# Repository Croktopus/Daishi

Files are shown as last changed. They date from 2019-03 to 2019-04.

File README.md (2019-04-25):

# Daishi

http://kb.metamechs.com/daishi/

I'm redesigning the Daishi-Prime (Daishi case that uses a plate), so stay tuned for that I guess.

If you're interested in designing your own keyboard, I recommend https://github.com/ruiqimao/keyboard-pcb-guide to learn PCB design, https://beta.docs.qmk.fm/ for how to use QMK, and https://www.youtube.com/watch?v=A5bc9c3S12g&list=PL40d7srwyc_Ow4aaOGXlP2idPGwD7ruKg to get started with Fusion 360.

Other invaluable resources:
* http://www.keyboard-layout-editor.com/ to design your layout
* http://builder.swillkb.com/ to generate a plate (though I do recommend doing it manually if it's going to be more complex than a rectangle with a few holes)
* https://discordapp.com/invite/Uq7gcHh for the QMK discord (super helpful folks who are way better at this than me)
* https://www.laserboost.com/ to get a metal plate cut
* https://www.ponoko.com/ to get an acrylic plate cut
* https://jlcpcb.com/ cheapest PCB manufacturer I've found

Check the BoM to find links to places where you can buy all the components for cheaper than I was able to.

All I ask is that if you do build one of these please send me pics!

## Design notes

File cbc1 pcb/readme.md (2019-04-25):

# Making a PCB

If you just want to have a CBC1 PCB printed, you'll want to take the gerbers.zip file to your PCB fab of choice (I recommend JLCPCB for the price), as well as the gerbers.zip in the daughterboard directory.

I've also got all the KiCad files in here if you want to play around with making your own modifications.

Once you have your PCB (unless you got it assembled for you), you get to do all the super fun SMT soldering! This is easily the worst part of the process IMO, but you can get through it in a few hours. If you haven't done this before, look up some youtube tutorials before you decide whether you want to.

Then you can tune your stabs, crimp a cable, and solder some switches (I recommend following Nathan Kim's guide for stabilizers, just without the band-aid mod).

Obviously this is super light on details, but...anything in here that you don't know how to do, just look it up. If you're still having trouble understanding something, I can answer some questions, but there are some fairly deep topics in here that already have great educational resources (EEVBlog for soldering, https://github.com/ruiqimao/keyboard-pcb-guide for KiCad, Nathan Kim's vids and streams for keeb building).

But that's pretty much the gist of it for getting a functional PCB for your Daishi build.

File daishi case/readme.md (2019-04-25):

# Building a Case

This should just be a (relatively) quick guide on how to create a case for a Daishi, which ended up being super complex.

Step 1 is 3D printing the pieces. If you have access to a large enough 3D printer, you can just print the top and bottom as complete pieces using the .stl's in this folder.

If you are a mere mortal like me, you'll have to split up both the top and bottom case into a few pieces each. I included some .stl's that have been pre-split into pieces small enough to fit near any 3D printer, with dovetails to make alignment easier.

I print at ~50% infill (I try to push it as high as possible, but at around the 75% mark I start to get severe issues with print quality), with a brim, and 0.2mm layer height (could bump it up to 0.3 without a real loss in quality). A problem with printing in multiple dovetailed pieces is that fitment has to be pretty precise, and brims can fuck that up if not removed carefully. You can get away with whatever blade you have on hand, but I recommend using a metal deburring tool like https://smile.amazon.com/Acrux7-Deburring-Remover-Plastic-Aluminum/dp/B077Z4T437/ if you're going to be doing this a lot - it's been a big improvement to my 3D printing QoL.

After you have the pieces, you'll want to ensure they all fit together nicely and glue them together (I recommend a medium or thicker CA glue). This is also where I'd recommend painting, if you want to do so.

Use a soldering iron to put in your brass threaded inserts (links in the BoM). You could try to secure 3D printed components with something like wood screws, but I wouldn't recommend it. Brass threaded inserts are going to be way more durable than any threads you tap in plastic, which will allow you to actually take it apart and put it back together a few times. Plus you can actually get some clamp with these threaded inserts, which is pretty important for a build with gasketing.

This is "optional", but it makes a huge difference. Take some 1.75mm transparent filament and shove it in the holes for the lock lights, using a flush cutter to get the top flush with the top of the top case (make sure the filament ends a few mm above the bottom of the hole, so that there's room for the LED). This makes for a really nice looking light pipe, and when the lights are off it almost just looks like the case material; I love the aesthetic.

Now it's time to apply the gasketing. Take your rubber of choice (I use neoprene, but It also works with EPDM and probably silicone and most any other rubber too) and start punching out holes. I got this cheap set off amazon https://smile.amazon.com/gp/product/B07BT47968 but the only sizes you need are 5mm, 2mm, and 7mm (and really 95% of the work is done with the 5mm punch, with the others only used for the standoffs with screw holes). Cut out a bunch of strips of rubber to go around the edge of the bottom case and the bottom of the top case (as seen in the photos), and glue everything in!

I use some blu-tack to hold down my cable that goes to the USB daughterboard (velcro would be nicer but I only had hooks on hand and no loops!)

You'll need 8 M3x12 screws for joining the top and bottom case, and 11 M2x4 screws to mount the keyboard PCB and daughterboard (though you could also forgo the 7 screws for the keyboard PCB and just rely on the gasketing). I also recommend using M2 fiber washers for the PCB screws (linked in the BoM).

That's pretty much it for building the case. Good luck!

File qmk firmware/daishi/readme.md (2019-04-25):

# Daishi

Daishi

A compact battlecruiser using the CBC1 PCB. [More info on kb.metamechs.com](http://kb.metamechs.com/daishi/)

Keyboard Maintainer: [Crokto](https://github.com/Croktopus/)  
Hardware Supported: CBC1 PCB  
Hardware Availability: [kb.metamechs.com](http://kb.metamechs.com/daishi/get-your-own-daishi/)

Make example for this keyboard (after setting up your build environment):

    make daishi:default

See the [build environment setup](https://docs.qmk.fm/#/getting_started_build_tools) and the [make instructions](https://docs.qmk.fm/#/getting_started_make_guide) for more information. Brand new to QMK? Start with our [Complete Newbs Guide](https://docs.qmk.fm/#/newbs).

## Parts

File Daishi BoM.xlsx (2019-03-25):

PCB |  |  |  |  |  |  | CASE |  |  |  |  |  |  | TIME
part | qty | link | price/ea | moq | extended price | qty price | product | qty | link | $/ea | moq | extended price | qty price | activity | hours | rate | total pay
.1u cap | 6 | https://lcsc.com/product-detail/Others_CCTC-TCC0805X7R104M500DT_C360619.html | 0.0046 | 50 | 0.23 | 0.0276 | m2 inserts | 11 | https://itworks3d.com/product/metric-brass-heat-set-insert-plastics/ | 0.21 | 1 | 2.31 | 2.31 | smd | 3.5 | 11 | 38.5
1u cap | 2 | https://lcsc.com/product-detail/Multilayer-Ceramic-Capacitors-MLCC-SMD-SMT_SAMSUNG_CL21F105ZOFNNNE_1uF-105-80-20-16V_C16834.html | 0.01 | 50 | 0.405 | 0.0162 | m3 inserts | 8 | https://itworks3d.com/product/metric-brass-heat-set-insert-plastics/ | 0.31 | 1 | 2.48 | 2.48 | tht | 1.5 | 11 | 16.5
22p cap | 2 | https://lcsc.com/product-detail/Multilayer-Ceramic-Capacitors-MLCC-SMD-SMT_22pF-220-5-50V_C24658.html | 0.01 | 50 | 0.3 | 0.012 | filament | 2 | https://www.matterhackers.com/store/l/175mm-pla-filament-grey-1-kg/sk/MPL0Q8ZD | 18.99 | 1 | 37.98 | 37.98 | case building | 1.5 | 11 | 16.5
4.7n cap | 1 | https://lcsc.com/product-detail/Multilayer-Ceramic-Capacitors-MLCC-SMD-SMT_MuRata_GRM2162C1H472JA01D_4-7nF-472-5-50V_C86029.html | 0.03 | 20 | 0.58 | 0.029 | neoprene | 1 | https://smile.amazon.com/gp/product/B076MHP8WJ/ref=ppx_yo_dt_b_asin_title_o03_s00?ie=UTF8&psc=1 | 11.68 | 1 | 11.68 | 11.68 | 3d printing | 80 | 0.5 | 40
10k res | 2 | https://lcsc.com/product-detail/Chip-Resistor-Surface-Mount_10KR-1002-1_C103904.html | 0.0018 | 100 | 0.18 | 0.0036 | sorbothane feet | 1 | https://smile.amazon.com/gp/product/B00YLLRMK0/ref=oh_aui_search_asin_title?ie=UTF8&psc=1 | 0.443 | 36 | 15.948 | 0.443
1k res | 4 | https://lcsc.com/product-detail/Chip-Resistor-Surface-Mount_1KR-1001-1_C103903.html | 0.0019 | 100 | 0.19 | 0.0076 | velcro | 1 | https://smile.amazon.com/PASS-IPass-FastLane-Mounting-Kit/dp/B01N5EH7R9?s=hi | 7.15 | 1 | 7.15 | 7.15 |  |  |  | 111.5
22 res | 2 | https://lcsc.com/product-detail/Others_Huaxin-S-T-WR08X22R0FTL_C334886.html | 0.0017 | 100 | 0.17 | 0.0034 | transparent filament (light pipes, optional) | 1 | https://smile.amazon.com/3D-Solutech-Filament-Dimensional-Accuracy/dp/B00MB3CV6K/ | 17.99 | 1 | 17.99 | 17.99
5.1k res | 2 | https://lcsc.com/product-detail/Chip-Resistor-Surface-Mount_5-1KR-5101-1_C84375.html | 0.0025 | 100 | 0.25 | 0.005 | m2 screws | 11 | https://smile.amazon.com/uxcell-M2x4mm-Thread-Button-Socket/dp/B01B1OD83Y?s=industrial | 0.0762 | 100 | 7.62 | 0.8382
1M res | 1 | https://lcsc.com/product-detail/Chip-Resistor-Surface-Mount_1MR-1004-1_C136578.html | 0.0017 | 100 | 0.17 | 0.0017 | m3 screws | 8 | https://smile.amazon.com/uxcell-M3x12mm-Socket-Screws-100Pcs/dp/B0143GZIHQ?s=industrial | 0.0999 | 100 | 9.99 | 0.7992
diode | 117 | https://lcsc.com/product-detail/Switching-Diode_1N4148W_C115103.html | 0.01 | 50 | 0.819 | 0.819
0805 led | 3 | https://lcsc.com/product-detail/Light-Emitting-Diodes-LED_Hongli-Zhihui-HONGLITRONIC-HL-PSC-2012H233W-8000-12000K_C219230.html | 0.03 | 20 | 0.532 | 0.0798 |  |  |  |  |  | 113.148 | 81.6704
rst sw | 1 | https://www.digikey.com/product-detail/en/e-switch/TL3342F160QG-TR/EG2531CT-ND/379004 | 0.65 | 1 | 0.65 | 0.65
90usb1286 | 1 | https://www.digikey.com/product-detail/en/microchip-technology/AT90USB1286-AU/AT90USB1286-AU-ND/2238141 | 8.09 | 1 | 8.09 | 8.09 |  |  |  |  |  |  |  | SHIPPING
16M xtal | 1 | https://www.digikey.com/product-detail/en/epson/FA-238-16.0000MB-C3/SER3686CT-ND/2403459 | 0.36 | 1 | 0.36 | 0.36 |  |  |  |  |  |  |  | source | total | # you net | $per
hro usbc | 1 | https://lcsc.com/product-detail/USB-Type-C_Korean-Hroparts-Elec-TYPE-C-31-M-12_C165948.html | 0.39 | 1 | 0.3882 | 0.3882 |  |  |  |  |  |  |  | lcsc | 5.18 | 5 | 1.036
1x4 recep | 2 | https://www.digikey.com/product-detail/en/te-connectivity-amp-connectors/280378-1/A106404-ND/1153244 | 0.93 | 1 | 1.86 | 1.86 |  |  |  |  |  |  |  | digikey | 13 | 5 | 2.6
1x4 plug | 2 | https://www.digikey.com/product-detail/en/te-connectivity-amp-connectors/280359/A121744-ND/2054280 | 0.35 | 1 | 0.7 | 0.7 |  |  |  |  |  |  |  | mouser | 7.99 | 5 | 1.598
crimp conn | 8 | https://www.digikey.com/product-detail/en/te-connectivity-amp-connectors/280708-2/A107044CT-ND/3488605 | 0.14 | 1 | 1.12 | 1.12 |  |  |  |  |  |  |  | IT-works | 11.15 | 5 | 2.23
1x4 wire | 1 | https://www.digikey.com/product-detail/en/adafruit-industries-llc/3892/1528-2695-ND/9603618 | 1.95 | 1 | 1.95 | 1.95 |  |  |  |  |  |  |  | jlcpcb | 16.98 | 5 | 3.396
 |  |  |  |  |  |  |  |  | you do the work |  | 333.0222 |  |  | novelkeys | 3.85 | 5 | 0.77
alps encoder | 1 | https://www.mouser.com/ProductDetail/688-EC11E1834403 | 5.38 | 1 | 5.38 | 5.38 |  |  | I do the work |  | 295.2972
keys witches | 116 | https://www.aliexpress.com/item/VK-JAPAN-SMK-original-New-genuine-imported-keyboard-switch-button-touch-2-foot-reset-switch/32845423584.html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 | 0.444 | 200 | 88.8 | 51.504 |  |  |  |  |  |  |  |  | 58.15 |  | 11.63
2u stabs | 4 | https://novelkeys.xyz/collections/miscellaneous/products/cherry-stabilizers?variant=3747938893864 | 2.00 | 1 | 8 | 8
6.25u stabs | 1 | https://novelkeys.xyz/collections/miscellaneous/products/cherry-stabilizers?variant=3747938893864 | 2.25 | 1 | 2.25 | 2.25
m2 washers | 21 | https://smile.amazon.com/gp/product/B01ARADX88/ref=oh_aui_search_asin_title?ie=UTF8&psc=1 | 0.07 | 100 | 6.97 | 1.4637
main pcb | 1 | https://jlcpcb.com/ | 5.276 | 5 | 26.38 | 5.276
daughterboard | 1 | https://jlcpcb.com/ | 0.5 | 10 | 5 | 0.5 | SHIPPING MATS
 |  |  |  |  |  |  | item | link | total | # netted | $per
 |  |  |  |  | 161.7242 | 90.4968 | kaizen | https://smile.amazon.com/gp/product/B007J2JJYK/ref=ppx_od_dt_b_asin_title_s00?ie=UTF8&psc=1 | 24.99 | 2 | 12.495
 |  |  |  |  |  |  | boxes | https://www.globalindustrial.com/product/itemKey/30396942 | 16.75 | 25 | 0.67
 |  |  |  |  |  |  |  |  |  |  | 13.165

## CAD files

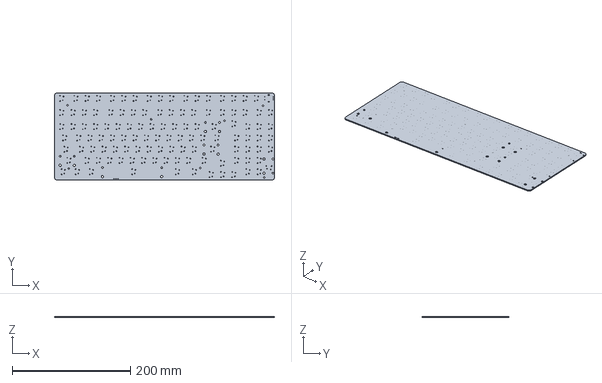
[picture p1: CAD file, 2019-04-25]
cbc1 pcb/cbc1.step
371.5 x 147.6 x 1.60 mm

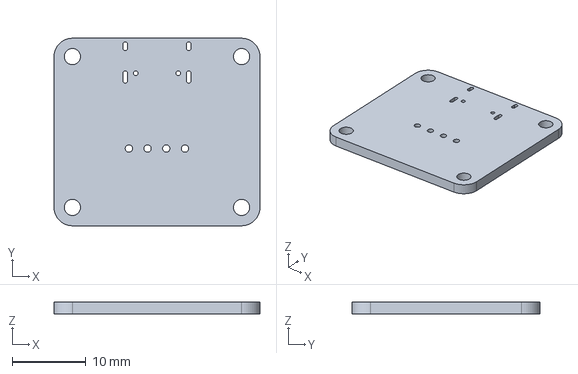
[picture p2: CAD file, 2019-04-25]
cbc1 pcb/usb breakout v2/usb breakouts.step
28.0 x 25.5 x 1.60 mm

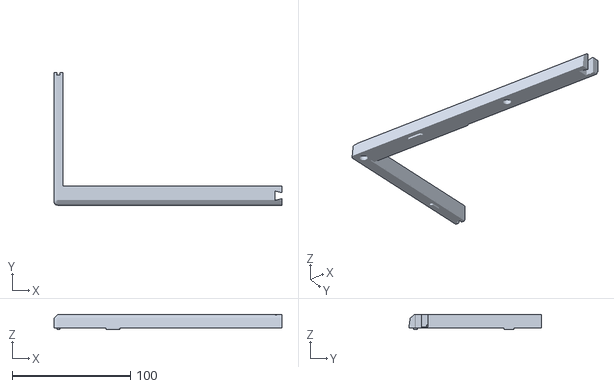
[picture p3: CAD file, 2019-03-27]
daishi case/3 way split for 3d printing/top se.stl
192.9 x 112.2 x 12.3

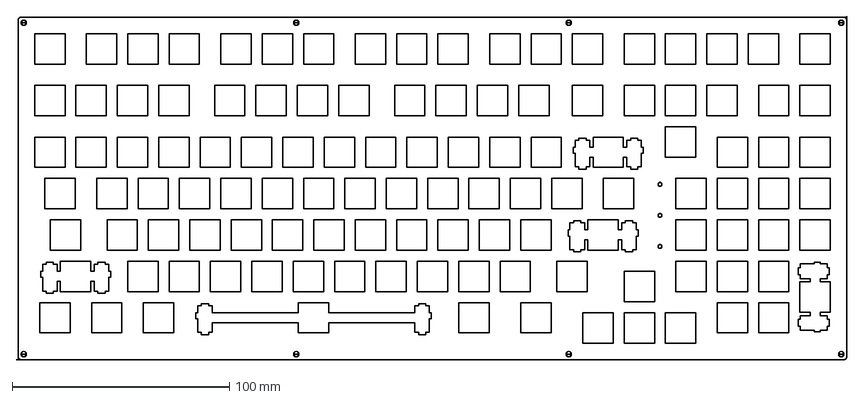
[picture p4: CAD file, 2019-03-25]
daishi case/plate.dxf
382.4 x 158.0 mm

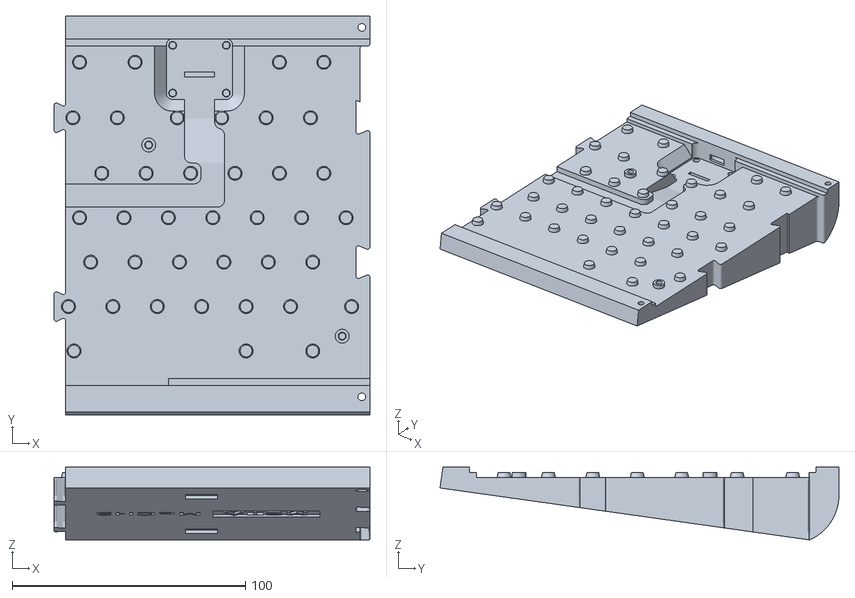
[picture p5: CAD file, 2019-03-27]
daishi case/3 way split for 3d printing/bot mid.stl
135.5 x 171.1 x 31.2

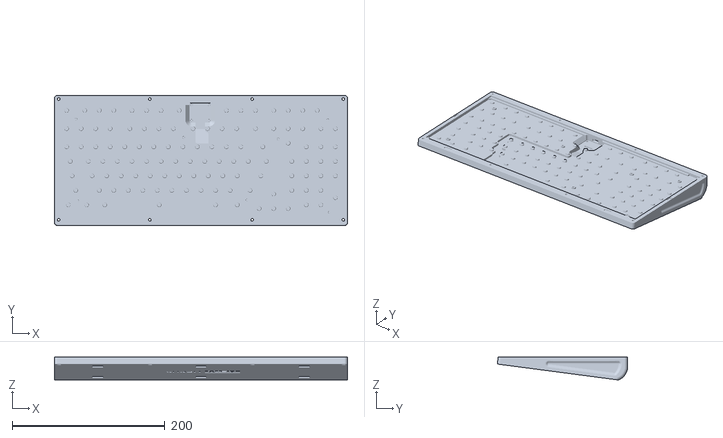
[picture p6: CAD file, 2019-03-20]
daishi case/daishi bottom case.stl
384.2 x 171.0 x 30.2

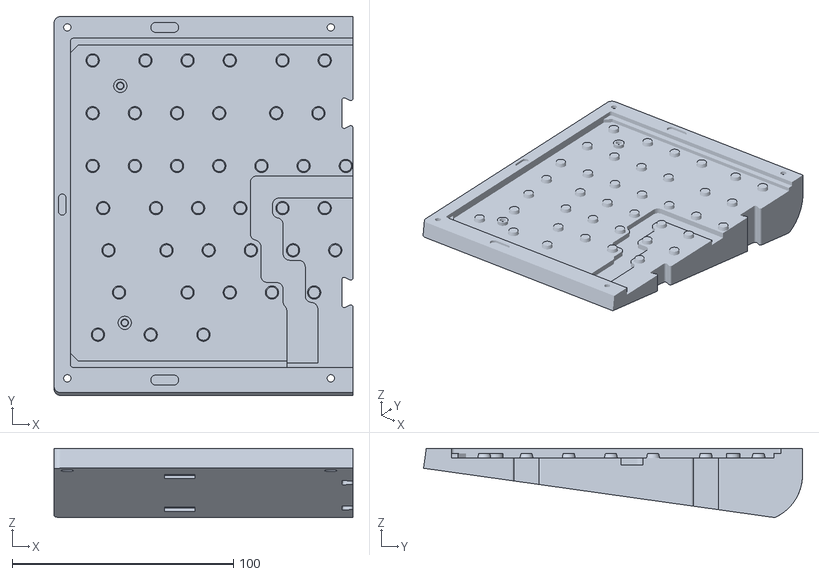
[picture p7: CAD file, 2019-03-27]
daishi case/3 way split for 3d printing/bot left.stl
135.0 x 171.1 x 31.2

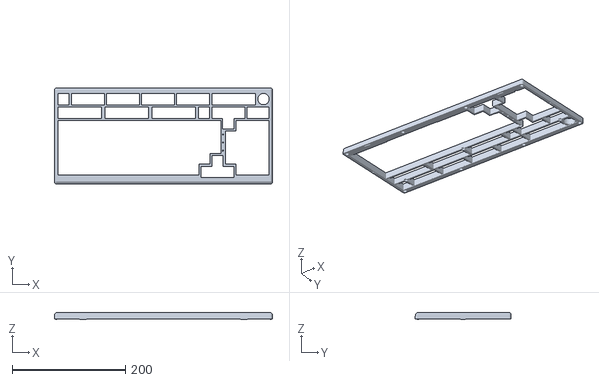
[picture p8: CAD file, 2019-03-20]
daishi case/daishi top case.stl
384.2 x 169.8 x 12.6

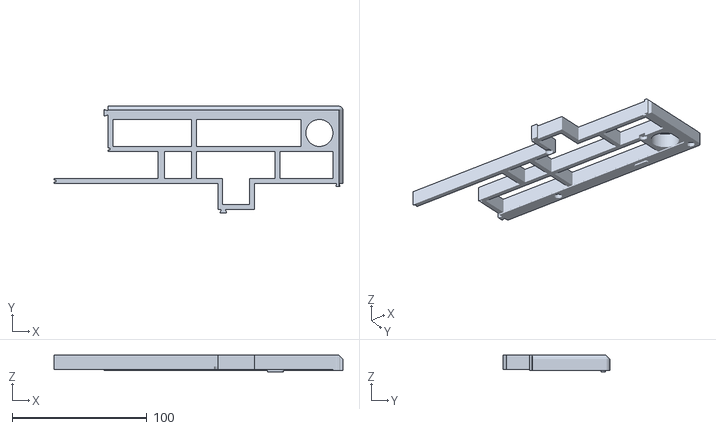
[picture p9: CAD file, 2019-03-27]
daishi case/3 way split for 3d printing/top nw.stl
214.2 x 79.0 x 12.3

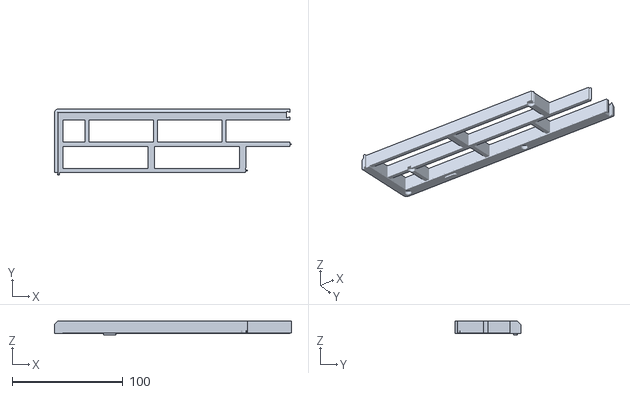
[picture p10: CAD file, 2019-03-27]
daishi case/3 way split for 3d printing/top ne.stl
214.4 x 59.4 x 12.3

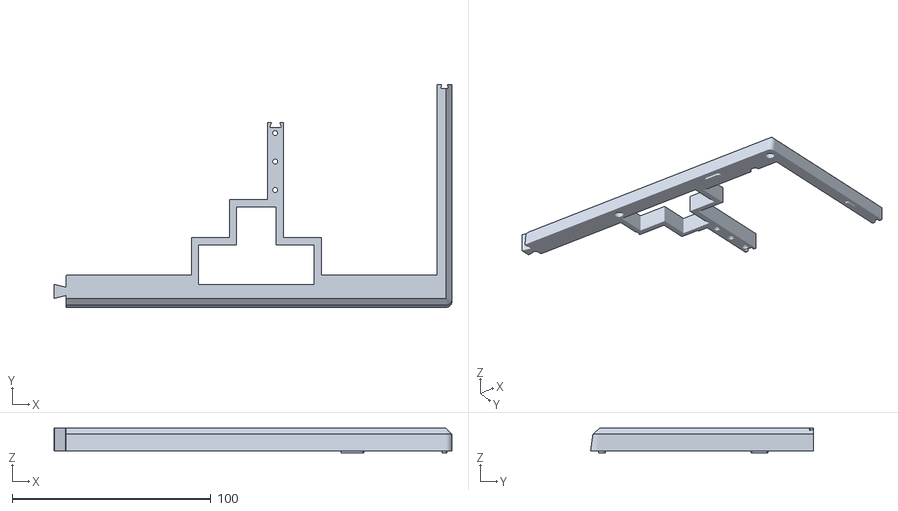
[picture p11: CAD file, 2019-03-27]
daishi case/3 way split for 3d printing/top sw.stl
200.1 x 112.1 x 12.3

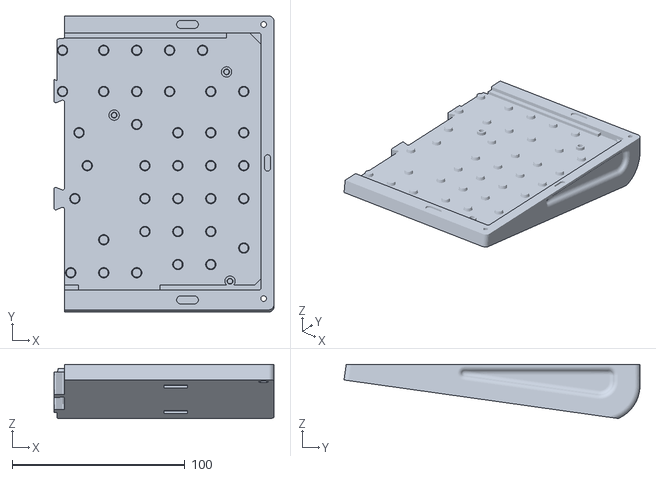
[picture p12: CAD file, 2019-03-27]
daishi case/3 way split for 3d printing/bot right.stl
127.2 x 171.1 x 31.2

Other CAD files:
daishi case/daishi.f3d

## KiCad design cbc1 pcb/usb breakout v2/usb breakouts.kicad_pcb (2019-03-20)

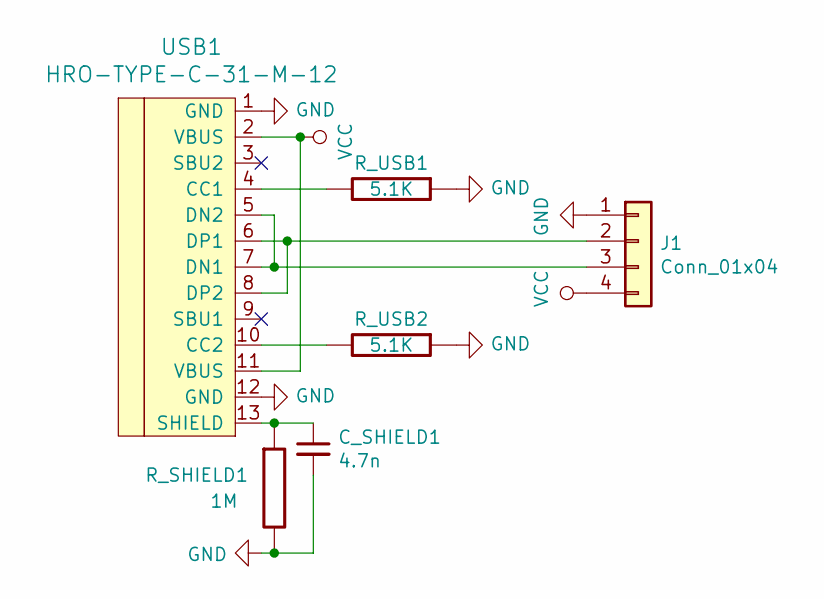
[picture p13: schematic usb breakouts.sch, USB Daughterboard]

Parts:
C_SHIELD1: 4.7n; C_0805_HandSoldering
J1: Conn_01x04; Pin_Header_Angled_1x04_Pitch2.54mm_centered
R_SHIELD1: 1M; R_0805_HandSoldering
R_USB1, R_USB2: 5.1K; R_0805_HandSoldering
USB1: HRO-TYPE-C-31-M-12; HRO-TYPE-C-31-M-12-HandSoldering

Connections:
GND: C_SHIELD1.2, J1.1, R_SHIELD1.2, R_USB1.1, R_USB2.1, USB1.1 (GND), USB1.12 (GND)
unnamed: C_SHIELD1.1, R_SHIELD1.1, USB1.13 (SHIELD)
unnamed: J1.2, USB1.6 (DP1), USB1.8 (DP2)
unnamed: J1.3, USB1.5 (DN2), USB1.7 (DN1)
unnamed: R_USB1.2, USB1.4 (CC1)
unnamed: R_USB2.2, USB1.10 (CC2)
VCC: J1.4, USB1.2 (VBUS), USB1.11 (VBUS)

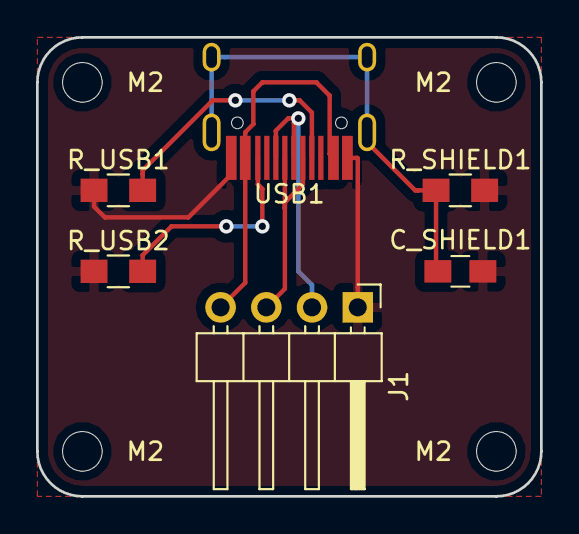
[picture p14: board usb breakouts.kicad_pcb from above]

Board: 2 copper layers, 28.0 x 25.5 mm, 10 parts (0 on the bottom side), 7 nets.

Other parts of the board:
M2, M2#2, M2#3, M2#4: MountingHole_2.2mm_M2

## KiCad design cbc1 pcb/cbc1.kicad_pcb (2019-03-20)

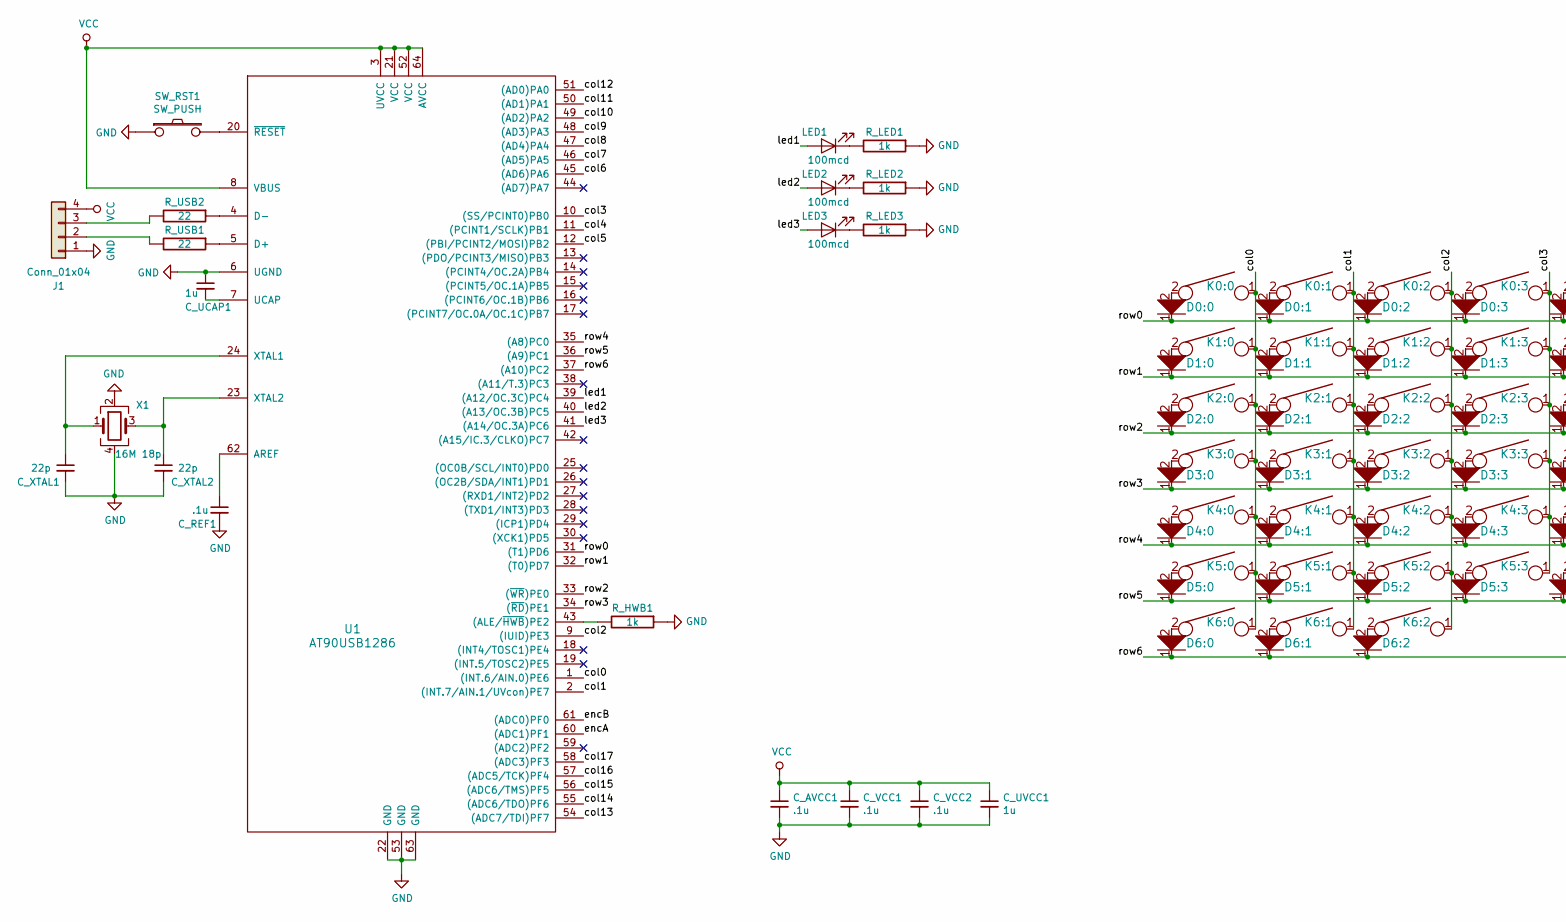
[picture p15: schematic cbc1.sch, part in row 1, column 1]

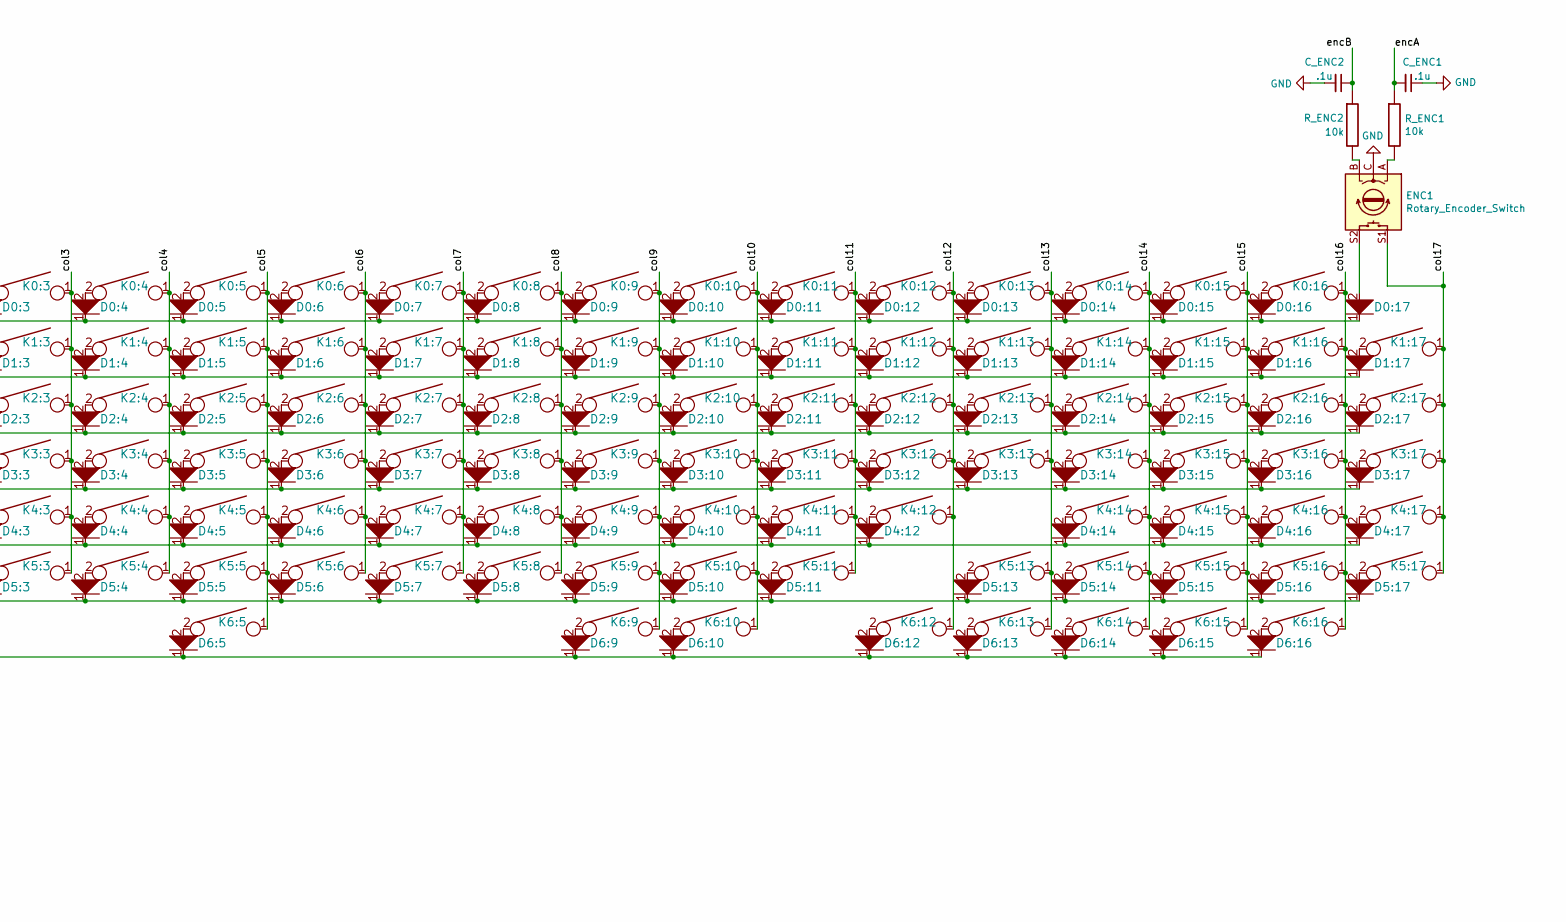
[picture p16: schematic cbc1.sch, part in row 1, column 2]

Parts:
C_AVCC1: .1u; C_0805_HandSoldering
C_ENC1, C_ENC2: .1u; C_0805_HandSoldering
C_REF1: .1u; C_0805_HandSoldering
C_UCAP1: 1u; C_0805_HandSoldering
C_UVCC1: 1u; C_0805_HandSoldering
C_VCC1, C_VCC2: .1u; C_0805_HandSoldering
C_XTAL1, C_XTAL2: 22p; C_0805_HandSoldering
D0:0, D0:1, D0:2, D0:3, D0:4, D0:5, D0:6, D0:7, D0:8, D0:9, D0:10, D0:11, D0:12, D0:13, D0:14, D0:15, D0:16, D0:17, D1:0, D1:1, D1:2, D1:3, D1:4, D1:5, D1:6, D1:7, D1:8, D1:9, D1:10, D1:11, D1:12, D1:13, D1:14, D1:15, D1:16, D1:17, D2:0, D2:1, D2:2, D2:3, D2:4, D2:5, D2:6, D2:7, D2:8, D2:9, D2:10, D2:11, D2:12, D2:13, D2:14, D2:15, D2:16, D2:17, D3:0, D3:1, D3:2, D3:3, D3:4, D3:5, D3:6, D3:7, D3:8, D3:9, D3:10, D3:11, D3:12, D3:13, D3:14, D3:15, D3:16, D3:17, D4:0, D4:1, D4:2, D4:3, D4:4, D4:5, D4:6, D4:7, D4:8, D4:9, D4:10, D4:11, D4:12, D4:14, D4:15, D4:16, D4:17, D5:0, D5:1, D5:2, D5:3, D5:4, D5:5, D5:6, D5:7, D5:8, D5:9, D5:10, D5:11, D5:13, D5:14, D5:15, D5:16, D5:17, D6:0, D6:1, D6:2, D6:5, D6:9, D6:10, D6:12, D6:13, D6:14, D6:15, D6:16: D; D_SOD123_hand
ENC1: Rotary_Encoder_Switch; RotaryEncoder_Alps_EC11E-Switch_Vertical_H20mm
J1: Conn_01x04; Pin_Header_Angled_1x04_Pitch2.54mm
K0:0, K0:1, K0:2, K0:3, K0:4, K0:5, K0:6, K0:7, K0:8, K0:9, K0:10, K0:11, K0:12, K0:13, K0:14, K0:15, K0:16, K1:0, K1:1, K1:2, K1:3, K1:4, K1:5, K1:6, K1:7, K1:8, K1:9, K1:10, K1:11, K1:12, K1:13, K1:14, K1:15, K1:16, K1:17, K2:0, K2:1, K2:2, K2:3, K2:4, K2:5, K2:6, K2:7, K2:8, K2:9, K2:10, K2:11, K2:12, K2:14, K2:15, K2:16, K2:17, K3:1, K3:2, K3:3, K3:4, K3:5, K3:6, K3:7, K3:8, K3:9, K3:10, K3:11, K3:12, K3:14, K3:15, K3:16, K3:17, K4:1, K4:2, K4:3, K4:4, K4:5, K4:6, K4:7, K4:8, K4:9, K4:10, K4:11, K4:14, K4:15, K4:16, K4:17, K5:1, K5:2, K5:3, K5:4, K5:5, K5:6, K5:7, K5:8, K5:9, K5:10, K5:13, K5:14, K5:15, K5:16, K6:12, K6:13, K6:14, K6:15, K6:16: KEYSW; SMK-PCB-100-90deg
K2:13, K5:17: KEYSW; SMK-PCB-200-90deg
K3:0, K3:13, K6:9, K6:10: KEYSW; SMK-PCB-150-90deg
K4:0, K5:11: KEYSW; SMK-PCB-175-90deg
K4:12, K5:0: KEYSW; SMK-PCB-225-90deg
K6:0, K6:1, K6:2: KEYSW; SMK-PCB-125-90deg
K6:5: KEYSW; SMK-PCB-625-90deg
LED1, LED2, LED3: 100mcd; LED_0805_HandSoldering
R_ENC1, R_ENC2: 10k; R_0805_HandSoldering
R_HWB1: 1k; R_0805_HandSoldering
R_LED1, R_LED2, R_LED3: 1k; R_0805_HandSoldering
R_USB1, R_USB2: 22; R_0805_HandSoldering
SW_RST1: SW_PUSH; SW_SPST_TL3342
U1: AT90USB1286; TQFP-64_14x14mm_Pitch0.8mm
X1: 16M 18p; Crystal_SMD_SeikoEpson_FA238-4pin_3.2x2.5mm_HandSoldering

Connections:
/col0: K0:0.1, K1:0.1, K2:0.1, K3:0.1, K4:0.1, K5:0.1, K6:0.1, U1.1 ((INT.6/AIN.0)PE6)
/col1: K0:1.1, K1:1.1, K2:1.1, K3:1.1, K4:1.1, K5:1.1, K6:1.1, U1.2 ((INT.7/AIN.1/UVcon)PE7)
/col2: K0:2.1, K1:2.1, K2:2.1, K3:2.1, K4:2.1, K5:2.1, K6:2.1, U1.9 ((IUID)PE3)
/col3: K0:3.1, K1:3.1, K2:3.1, K3:3.1, K4:3.1, K5:3.1, U1.10 ((SS/PCINT0)PB0)
/col4: K0:4.1, K1:4.1, K2:4.1, K3:4.1, K4:4.1, K5:4.1, U1.11 ((PCINT1/SCLK)PB1)
/col5: K0:5.1, K1:5.1, K2:5.1, K3:5.1, K4:5.1, K5:5.1, K6:5.1, U1.12 ((PBI/PCINT2/MOSI)PB2)
/col6: K0:6.1, K1:6.1, K2:6.1, K3:6.1, K4:6.1, K5:6.1, U1.45 ((AD6)PA6)
/col7: K0:7.1, K1:7.1, K2:7.1, K3:7.1, K4:7.1, K5:7.1, U1.46 ((AD5)PA5)
/col8: K0:8.1, K1:8.1, K2:8.1, K3:8.1, K4:8.1, K5:8.1, U1.47 ((AD4)PA4)
/col9: K0:9.1, K1:9.1, K2:9.1, K3:9.1, K4:9.1, K5:9.1, K6:9.1, U1.48 ((AD3)PA3)
/col10: K0:10.1, K1:10.1, K2:10.1, K3:10.1, K4:10.1, K5:10.1, K6:10.1, U1.49 ((AD2)PA2)
/col11: K0:11.1, K1:11.1, K2:11.1, K3:11.1, K4:11.1, K5:11.1, U1.50 ((AD1)PA1)
/col12: K0:12.1, K1:12.1, K2:12.1, K3:12.1, K4:12.1, K6:12.1, U1.51 ((AD0)PA0)
/col13: K0:13.1, K1:13.1, K2:13.1, K3:13.1, K5:13.1, K6:13.1, U1.54 ((ADC7/TDI)PF7)
/col14: K0:14.1, K1:14.1, K2:14.1, K3:14.1, K4:14.1, K5:14.1, K6:14.1, U1.55 ((ADC6/TDO)PF6)
/col15: K0:15.1, K1:15.1, K2:15.1, K3:15.1, K4:15.1, K5:15.1, K6:15.1, U1.56 ((ADC6/TMS)PF5)
/col16: K0:16.1, K1:16.1, K2:16.1, K3:16.1, K4:16.1, K5:16.1, K6:16.1, U1.57 ((ADC5/TCK)PF4)
/col17: ENC1.S1, K1:17.1, K2:17.1, K3:17.1, K4:17.1, K5:17.1, U1.58 ((ADC3)PF3)
/encA: C_ENC1.2, R_ENC1.1, U1.60 ((ADC1)PF1)
/encB: C_ENC2.1, R_ENC2.1, U1.61 ((ADC0)PF0)
/led1: LED1.2 (A), U1.39 ((A12/OC.3C)PC4)
/led2: LED2.2 (A), U1.40 ((A13/OC.3B)PC5)
/led3: LED3.2 (A), U1.41 ((A14/OC.3A)PC6)
/row0: D0:0.1, D0:1.1, D0:2.1, D0:3.1, D0:4.1, D0:5.1, D0:6.1, D0:7.1, D0:8.1, D0:9.1, D0:10.1, D0:11.1, D0:12.1, D0:13.1, D0:14.1, D0:15.1, D0:16.1, D0:17.1, U1.31 ((T1)PD6)
/row1: D1:0.1, D1:1.1, D1:2.1, D1:3.1, D1:4.1, D1:5.1, D1:6.1, D1:7.1, D1:8.1, D1:9.1, D1:10.1, D1:11.1, D1:12.1, D1:13.1, D1:14.1, D1:15.1, D1:16.1, D1:17.1, U1.32 ((T0)PD7)
/row2: D2:0.1, D2:1.1, D2:2.1, D2:3.1, D2:4.1, D2:5.1, D2:6.1, D2:7.1, D2:8.1, D2:9.1, D2:10.1, D2:11.1, D2:12.1, D2:13.1, D2:14.1, D2:15.1, D2:16.1, D2:17.1, U1.33 ((~WR~)PE0)
/row3: D3:0.1, D3:1.1, D3:2.1, D3:3.1, D3:4.1, D3:5.1, D3:6.1, D3:7.1, D3:8.1, D3:9.1, D3:10.1, D3:11.1, D3:12.1, D3:13.1, D3:14.1, D3:15.1, D3:16.1, D3:17.1, U1.34 ((~RD~)PE1)
/row4: D4:0.1, D4:1.1, D4:2.1, D4:3.1, D4:4.1, D4:5.1, D4:6.1, D4:7.1, D4:8.1, D4:9.1, D4:10.1, D4:11.1, D4:12.1, D4:14.1, D4:15.1, D4:16.1, D4:17.1, U1.35 ((A8)PC0)
/row5: D5:0.1, D5:1.1, D5:2.1, D5:3.1, D5:4.1, D5:5.1, D5:6.1, D5:7.1, D5:8.1, D5:9.1, D5:10.1, D5:11.1, D5:13.1, D5:14.1, D5:15.1, D5:16.1, D5:17.1, U1.36 ((A9)PC1)
/row6: D6:0.1, D6:1.1, D6:2.1, D6:5.1, D6:9.1, D6:10.1, D6:12.1, D6:13.1, D6:14.1, D6:15.1, D6:16.1, U1.37 ((A10)PC2)
GND: C_AVCC1.2, C_ENC1.1, C_ENC2.2, C_REF1.2, C_UCAP1.1, C_UVCC1.2, C_VCC1.2, C_VCC2.2, C_XTAL1.2, C_XTAL2.2, ENC1.C, J1.1, R_HWB1.1, R_LED1.1, R_LED2.1, R_LED3.1, SW_RST1.1, U1.6 (UGND), U1.22 (GND), U1.53 (GND), U1.63 (GND), X1.2, X1.4
unnamed: C_REF1.1, U1.62 (AREF)
unnamed: C_UCAP1.2, U1.7 (UCAP)
unnamed: C_XTAL1.1, U1.24 (XTAL1), X1.1
unnamed: C_XTAL2.1, U1.23 (XTAL2), X1.3
unnamed: D0:0.2, K0:0.2
unnamed: D0:1.2, K0:1.2
unnamed: D0:2.2, K0:2.2
unnamed: D0:3.2, K0:3.2
unnamed: D0:4.2, K0:4.2
unnamed: D0:5.2, K0:5.2
unnamed: D0:6.2, K0:6.2
unnamed: D0:7.2, K0:7.2
unnamed: D0:8.2, K0:8.2
unnamed: D0:9.2, K0:9.2
unnamed: D0:10.2, K0:10.2
unnamed: D0:11.2, K0:11.2
unnamed: D0:12.2, K0:12.2
unnamed: D0:13.2, K0:13.2
unnamed: D0:14.2, K0:14.2
unnamed: D0:15.2, K0:15.2
unnamed: D0:16.2, K0:16.2
unnamed: D0:17.2, ENC1.S2
unnamed: D1:0.2, K1:0.2
unnamed: D1:1.2, K1:1.2
unnamed: D1:2.2, K1:2.2
unnamed: D1:3.2, K1:3.2
unnamed: D1:4.2, K1:4.2
unnamed: D1:5.2, K1:5.2
unnamed: D1:6.2, K1:6.2
unnamed: D1:7.2, K1:7.2
unnamed: D1:8.2, K1:8.2
unnamed: D1:9.2, K1:9.2
unnamed: D1:10.2, K1:10.2
unnamed: D1:11.2, K1:11.2
unnamed: D1:12.2, K1:12.2
unnamed: D1:13.2, K1:13.2
unnamed: D1:14.2, K1:14.2
unnamed: D1:15.2, K1:15.2
unnamed: D1:16.2, K1:16.2
unnamed: D1:17.2, K1:17.2
unnamed: D2:0.2, K2:0.2
unnamed: D2:1.2, K2:1.2
unnamed: D2:2.2, K2:2.2
unnamed: D2:3.2, K2:3.2
unnamed: D2:4.2, K2:4.2
unnamed: D2:5.2, K2:5.2
unnamed: D2:6.2, K2:6.2
unnamed: D2:7.2, K2:7.2
unnamed: D2:8.2, K2:8.2
unnamed: D2:9.2, K2:9.2
unnamed: D2:10.2, K2:10.2
unnamed: D2:11.2, K2:11.2
unnamed: D2:12.2, K2:12.2
unnamed: D2:13.2, K2:13.2
unnamed: D2:14.2, K2:14.2
unnamed: D2:15.2, K2:15.2
unnamed: D2:16.2, K2:16.2
unnamed: D2:17.2, K2:17.2
unnamed: D3:0.2, K3:0.2
unnamed: D3:1.2, K3:1.2
unnamed: D3:2.2, K3:2.2
unnamed: D3:3.2, K3:3.2
unnamed: D3:4.2, K3:4.2
unnamed: D3:5.2, K3:5.2
unnamed: D3:6.2, K3:6.2
unnamed: D3:7.2, K3:7.2
unnamed: D3:8.2, K3:8.2
unnamed: D3:9.2, K3:9.2
unnamed: D3:10.2, K3:10.2
unnamed: D3:11.2, K3:11.2
unnamed: D3:12.2, K3:12.2
unnamed: D3:13.2, K3:13.2
unnamed: D3:14.2, K3:14.2
unnamed: D3:15.2, K3:15.2
unnamed: D3:16.2, K3:16.2
unnamed: D3:17.2, K3:17.2
unnamed: D4:0.2, K4:0.2
unnamed: D4:1.2, K4:1.2
unnamed: D4:2.2, K4:2.2
unnamed: D4:3.2, K4:3.2
unnamed: D4:4.2, K4:4.2
unnamed: D4:5.2, K4:5.2
unnamed: D4:6.2, K4:6.2
unnamed: D4:7.2, K4:7.2
unnamed: D4:8.2, K4:8.2
unnamed: D4:9.2, K4:9.2
unnamed: D4:10.2, K4:10.2
unnamed: D4:11.2, K4:11.2
unnamed: D4:12.2, K4:12.2
unnamed: D4:14.2, K4:14.2
unnamed: D4:15.2, K4:15.2
unnamed: D4:16.2, K4:16.2
unnamed: D4:17.2, K4:17.2
unnamed: D5:0.2, K5:0.2
unnamed: D5:1.2, K5:1.2
unnamed: D5:2.2, K5:2.2
unnamed: D5:3.2, K5:3.2
unnamed: D5:4.2, K5:4.2
unnamed: D5:5.2, K5:5.2
unnamed: D5:6.2, K5:6.2
unnamed: D5:7.2, K5:7.2
unnamed: D5:8.2, K5:8.2
unnamed: D5:9.2, K5:9.2
unnamed: D5:10.2, K5:10.2
unnamed: D5:11.2, K5:11.2
unnamed: D5:13.2, K5:13.2
unnamed: D5:14.2, K5:14.2
unnamed: D5:15.2, K5:15.2
unnamed: D5:16.2, K5:16.2
unnamed: D5:17.2, K5:17.2
unnamed: D6:0.2, K6:0.2
unnamed: D6:1.2, K6:1.2
unnamed: D6:2.2, K6:2.2
unnamed: D6:5.2, K6:5.2
unnamed: D6:9.2, K6:9.2
unnamed: D6:10.2, K6:10.2
unnamed: D6:12.2, K6:12.2
unnamed: D6:13.2, K6:13.2
unnamed: D6:14.2, K6:14.2
unnamed: D6:15.2, K6:15.2
unnamed: D6:16.2, K6:16.2
unnamed: ENC1.A, R_ENC1.2
unnamed: ENC1.B, R_ENC2.2
unnamed: J1.2, R_USB1.2
unnamed: J1.3, R_USB2.2
unnamed: LED1.1 (K), R_LED1.2
unnamed: LED2.1 (K), R_LED2.2
unnamed: LED3.1 (K), R_LED3.2
unnamed: R_HWB1.2, U1.43 ((ALE/~HWB~)PE2)
unnamed: R_USB1.1, U1.5 (D+)
unnamed: R_USB2.1, U1.4 (D-)
unnamed: SW_RST1.2, U1.20 (~RESET)
VCC: C_AVCC1.1, C_UVCC1.1, C_VCC1.1, C_VCC2.1, J1.4, U1.3 (UVCC), U1.8 (VBUS), U1.21 (VCC), U1.52 (VCC), U1.64 (AVCC)

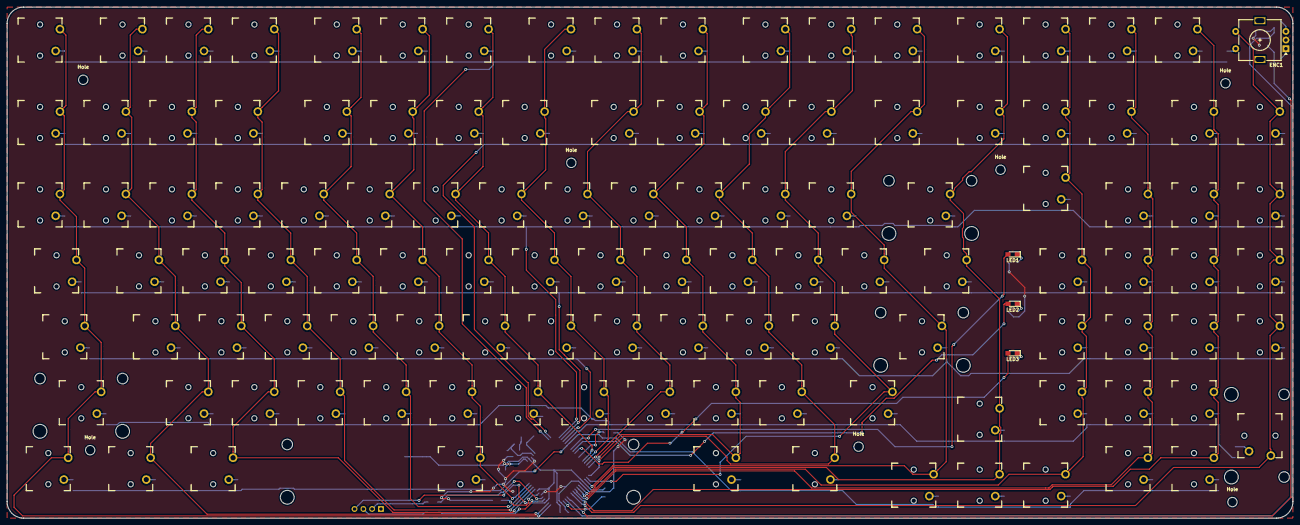
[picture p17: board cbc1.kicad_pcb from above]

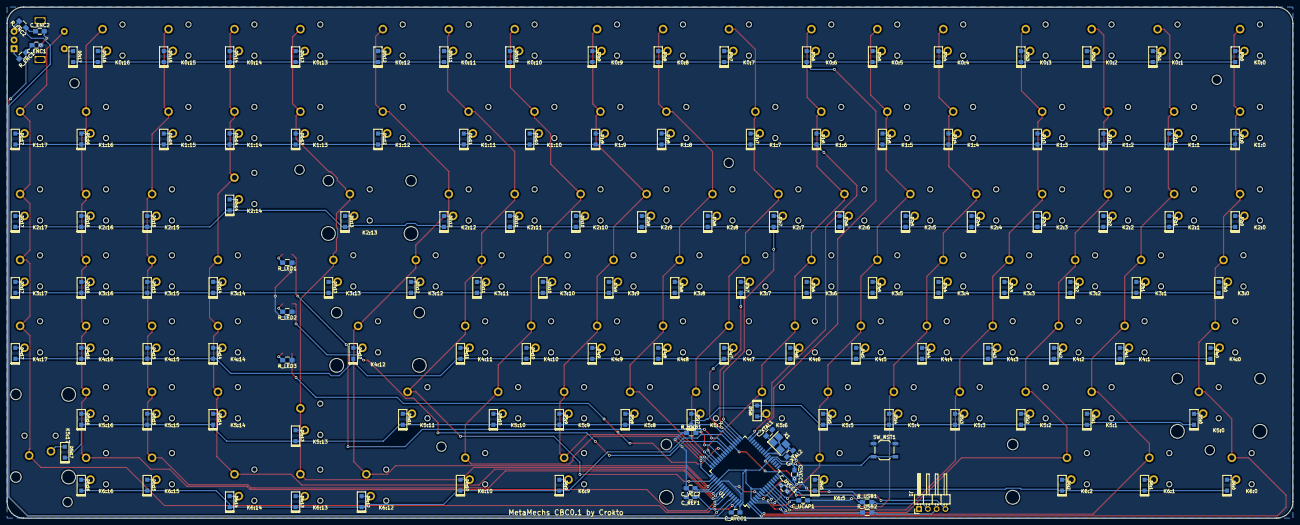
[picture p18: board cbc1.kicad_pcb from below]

Board: 2 copper layers, 371.5 x 147.6 mm, 266 parts (139 on the bottom side), 164 nets.

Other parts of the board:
Hole: M2.5; MountingHole_2.7mm_M2.5
Hole#2, Hole#3, Hole#4, Hole#5, Hole#6, Hole#7: M2.5; MountingHole_2.7mm_M2.5

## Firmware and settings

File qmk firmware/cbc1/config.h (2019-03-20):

/*
Copyright 2018 Chris Grossman

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
You should have received a copy of the GNU General Public License
along with this program.  If not, see <http://www.gnu.org/licenses/>.
*/

#ifndef CONFIG_H
#define CONFIG_H

#include "config_common.h"

/* USB Device descriptor parameter */
#define VENDOR_ID       0x6D6D
#define PRODUCT_ID      0x4323
#define DEVICE_VER      0x0001
#define MANUFACTURER    Crokto
#define PRODUCT         CBC
#define DESCRIPTION     Compact Battle Cruiser

/* key matrix size */
#define MATRIX_ROWS 7
#define MATRIX_COLS 18

/*
 * Keyboard Matrix Assignments
 *
 * Change this to how you wired your keyboard
 * COLS: AVR pins used for columns, left to right
 * ROWS: AVR pins used for rows, top to bottom
 * DIODE_DIRECTION: COL2ROW = COL = Anode (+), ROW = Cathode (-, marked on diode)
 *                  ROW2COL = ROW = Anode (+), COL = Cathode (-, marked on diode)
 *
*/
#define MATRIX_ROW_PINS { D6, D7, E0, E1, C0, C1, C2 }
#define MATRIX_COL_PINS { E6, E7, E3, B0, B1, B2, A6, A5, A4, A3, A2, A1, A0, F7, F6, F5, F4, F3 }
#define UNUSED_PINS

/* COL2ROW, ROW2COL, or CUSTOM_MATRIX */
#define DIODE_DIRECTION COL2ROW

/* Debounce reduces chatter (unintended double-presses) - set 0 if debouncing is not needed */
#define DEBOUNCING_DELAY 5

/* Set up rotary encoder */
#define NUMBER_OF_ENCODERS 1
#define ENCODERS_PAD_A { F1 }
#define ENCODERS_PAD_B { F0 }
#define ENCODER_RESOLUTION 2

#endif

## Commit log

2019-03-20 adding local versions
    [3d print friendly.f3d, bot left.stl, bot mid.stl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]
2019-03-20 changing name of f3d file
    [daishi.f3d]
2019-03-25 updating top case gaps, adding plate file
    [plate.dxf, top bot.stl, top left.stl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]
2019-03-25 added bom
    [Daishi BoM.xlsx]
2019-03-27 updating files
    readme, stls, f3d
    [bot left.stl, bot mid.stl, bot right.stl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]
2019-03-29 updated case readme
2019-04-25 Reformatted firmware
    [cbc1.step, usb breakouts.step]

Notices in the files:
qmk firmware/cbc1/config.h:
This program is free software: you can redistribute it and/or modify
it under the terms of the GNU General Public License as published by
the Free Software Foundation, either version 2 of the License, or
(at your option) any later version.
